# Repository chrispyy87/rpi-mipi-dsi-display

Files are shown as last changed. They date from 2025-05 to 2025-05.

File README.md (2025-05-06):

# rpi-mipi-dsi-display
Raspberry CM4 MIPI DSI display shield with LED driver for Midas MDT0500B1IH-MIPI display https://midasdisplays.com/shop/tft/mdt0500b1ih-mipi/ employing the ILI9881C display driver.
This shield serves as a example on how to implement alternative MIPI DSI displays to currently support ones.
PCBA manufacturing was realized by JLCPCB.

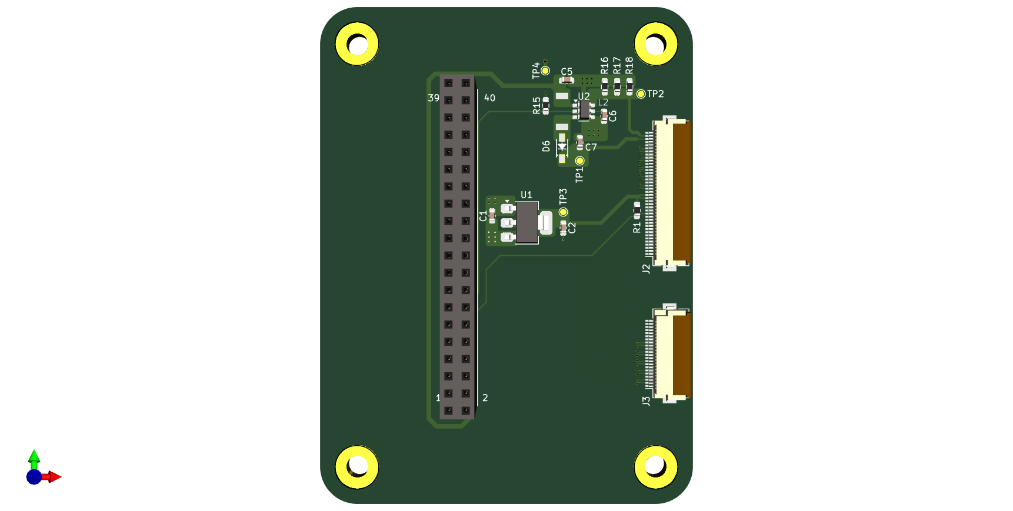
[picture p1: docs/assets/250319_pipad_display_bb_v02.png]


## Contents
- KiCAD schematics/board files: [CAD](CAD/)
- Gerber files: [rpi-mipi-dsi-display.zip](CAD/production/rpi-mipi-dsi-display.zip)
- PDF of schematics: [rpi-mipi-dsi-display.pdf](CAD/rpi-mipi-dsi-display.pdf)
- Bill of Materials: [rpi-mipi-dsi-display-BOM.xlsx](CAD/assembly/rpi-mipi-dsi-display-BOM.xlsx)
- KiCAD PCB and pick & place files: [rpi-mipi-dsi-display_CPL1.xlsx](CAD/assembly/rpi-mipi-dsi-display_CPL1.xlsx)

## Status
Working prototype with CM4 IO board running RPI OS Bookworm (64 bit).
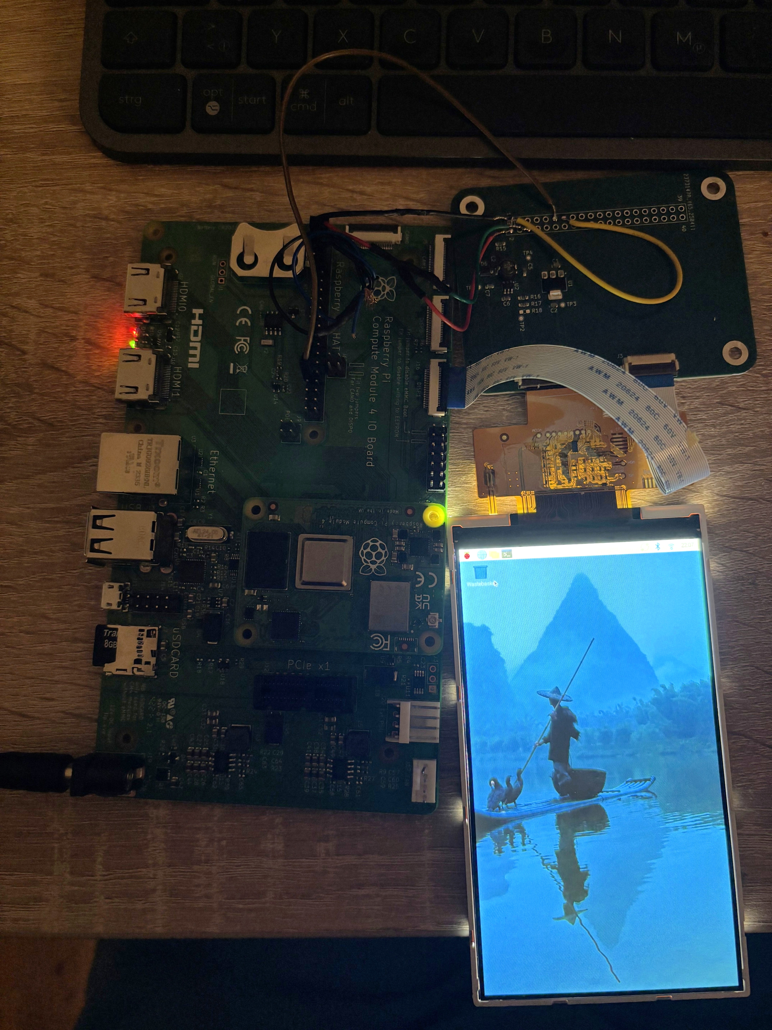
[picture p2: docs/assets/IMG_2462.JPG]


## Copyright and License
Schematic and PCB layout files are licensed under the CC BY 4.0 license.

THE DESIGN IS PROVIDED "AS IS" AND THE AUTHOR DISCLAIMS ALL WARRANTIES WITH REGARD TO THIS DESIGN INCLUDING ALL IMPLIED WARRANTIES OF MERCHANTABILITY AND FITNESS. IN NO EVENT SHALL THE AUTHOR BE LIABLE FOR ANY SPECIAL, DIRECT, INDIRECT, OR CONSEQUENTIAL DAMAGES OR ANY DAMAGES WHATSOEVER RESULTING FROM LOSS OF USE, DATA OR PROFITS, WHETHER IN AN ACTION OF CONTRACT, NEGLIGENCE OR OTHER TORTIOUS ACTION, ARISING OUT OF OR IN CONNECTION WITH THE USE OR PERFORMANCE OF THIS DESIGN.

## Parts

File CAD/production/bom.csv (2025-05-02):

Designator | Footprint | Quantity | Value | LCSC Part #
C1, C2 | 0603 | 2 | 22uF
C5, C6 | 0603 | 2 | 4.7uF
C7 | 0603 | 1 | 1uF
D6 | SOD-123 | 1 | MBR0540T1G
J1 | PinSocket_2x20_P2.54mm_Vertical | 1 | Conn_02x20_Odd_Even
J2 | Hirose_FH12-40S-0.5SH_1x40-1MP_P0.50mm_Horizontal_PiPad | 1 | Conn_01x40
J3 | Hirose_FH12-22S-0.5SH_1x22-1MP_P0.50mm_Horizontal_PiPad | 1 | Conn_01x22
L2 | SD53-100-R | 1 | 10uH 20%
R1, R15 | 0603 | 2 | 10k | RC0603FR-072K2L
R16 | 0603 | 1 | 2 | RC0603FR-072K2L
R17 | 0603 | 1 | 3.3 | RC0603FR-072K2L
TP1, TP2, TP3, TP4 | TestPoint_Pad_D1.0mm | 4 | TestPoint
U1 | SOT-223-3_TabPin2 | 1 | AMS1117-1.8
U2 | SOT-23-6 | 1 | TPS61165DBV

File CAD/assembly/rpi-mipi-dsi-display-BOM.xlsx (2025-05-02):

Comment | Designator | Footprint | JLCPCB Part #（optional）
MBR0540T1G | D6 |  | C21353
AMS1117-1.8 | U1 |  | C6185
TPS61165DBV | U2 |  | C58756
Hirose_FH12-22S-0.5SH_1x22-1MP_P0.50mm_Horizontal | J3 |  | C597981
Hirose_FH12-40S-0.5SH_1x40-1MP_P0.50mm_Horizontal | J2 |  | C202114
22uF | C1, C2 | 0603 | C59461
4.7uF | C5, C6 | 0603 | C19666
1uF | C7 | 0603 | C15849
10k | R1, R15 | 0603 | C25804
2 | R16 | 0603 | C22977
3.3 | R17 | 0603 | C22979
10uH 20% | L2 |  | C7309744

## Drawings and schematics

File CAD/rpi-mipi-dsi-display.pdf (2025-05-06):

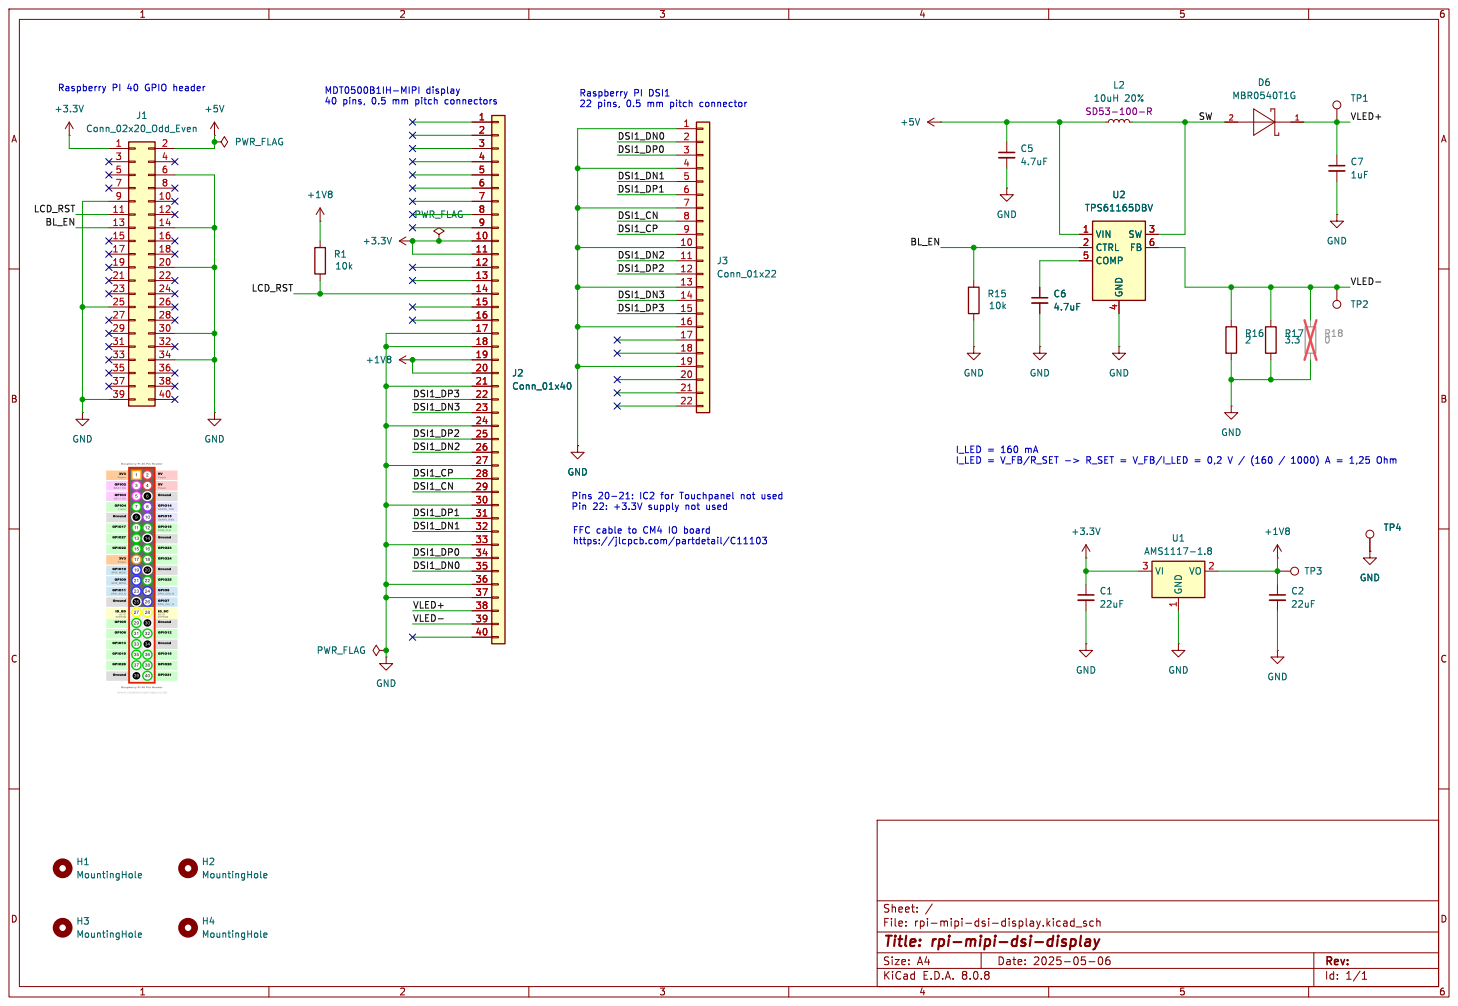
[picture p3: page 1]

Raspberry PI 40 GPIO header
+5V GND

22 pins, 0.5 mm pitch connector J2Conn_01x40

1 VO 2 VI 3 U1 AMS1117-1.8 DSI1_DN0 DSI1_DN3 DSI1_DN1 VLED+ VLED- BL_EN

File: rpi-mipi-dsi-display.kicad_sch Sheet: /
Id: 1/1 Title: rpi-mipi-dsi-display

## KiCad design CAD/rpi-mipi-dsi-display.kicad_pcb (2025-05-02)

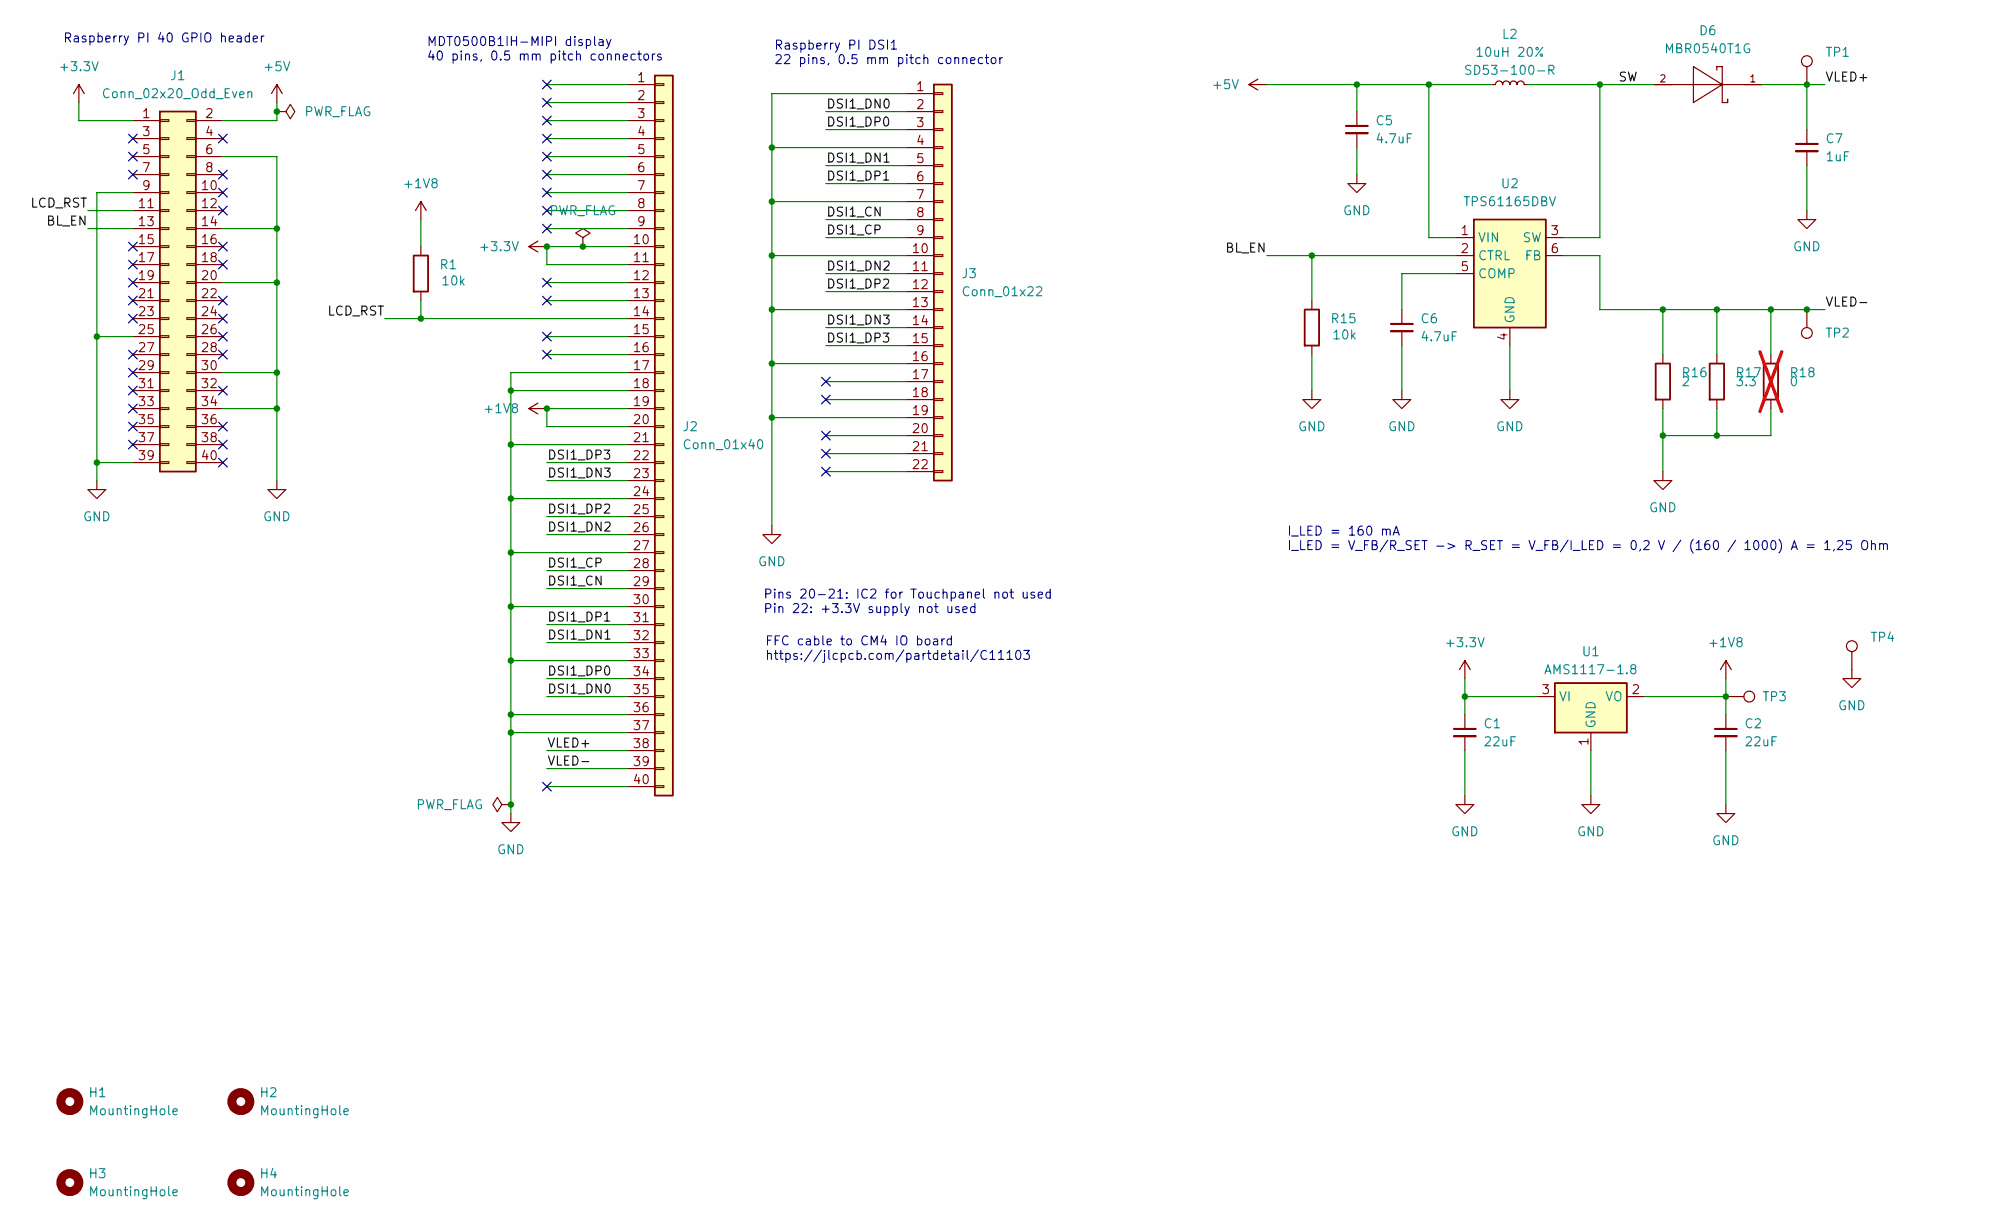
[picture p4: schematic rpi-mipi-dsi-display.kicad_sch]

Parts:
C1, C2: 22uF; C_0603_1608Metric
C5, C6: 4.7uF; C_0603_1608Metric
C7: 1uF; C_0603_1608Metric
D6: MBR0540T1G; SOD-123; MANUFACTURER_PART_NUMBER MBR0540T1G
H1, H2, H3, H4: MountingHole; MountingHole_3.5mm_Pad
J1: Conn_02x20_Odd_Even; PinSocket_2x20_P2.54mm_Vertical
J2: Conn_01x40; Hirose_FH12-40S-0.5SH_1x40-1MP_P0.50mm_Horizontal_PiPad
J3: Conn_01x22; Hirose_FH12-22S-0.5SH_1x22-1MP_P0.50mm_Horizontal_PiPad
L2: 10uH 20%; SD53-100-R
R1, R15: 10k; R_0603_1608Metric_Pad0.98x0.95mm_HandSolder; MPN RC0603FR-072K2L; Digi-Key_PN 311-2.20KHRCT-ND
R16: 2; R_0603_1608Metric_Pad0.98x0.95mm_HandSolder; MPN RC0603FR-072K2L; Digi-Key_PN 311-2.20KHRCT-ND
R17: 3.3; R_0603_1608Metric_Pad0.98x0.95mm_HandSolder; MPN RC0603FR-072K2L; Digi-Key_PN 311-2.20KHRCT-ND
R18: 0; R_0603_1608Metric_Pad0.98x0.95mm_HandSolder; MPN RC0603FR-072K2L; Digi-Key_PN 311-2.20KHRCT-ND; not fitted
TP1, TP2, TP3, TP4: TestPoint; TestPoint_Pad_D1.0mm
U1: AMS1117-1.8; SOT-223-3_TabPin2
U2: TPS61165DBV; SOT-23-6

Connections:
+1V8: C2.1, J2.19, J2.20, R1.1, TP3.1, U1.2 (VO)
+3.3V: C1.1, J1.1, J2.10, J2.11, U1.3 (VI)
+5V: C5.1, J1.2, L2.1, U2.1 (VIN)
/BL_EN: J1.13, R15.1, U2.2 (CTRL)
/DSI1_CN: J2.29, J3.8
/DSI1_CP: J2.28, J3.9
/DSI1_DN0: J2.35, J3.2
/DSI1_DN1: J2.32, J3.5
/DSI1_DN2: J2.26, J3.11
/DSI1_DN3: J2.23, J3.14
/DSI1_DP0: J2.34, J3.3
/DSI1_DP1: J2.31, J3.6
/DSI1_DP2: J2.25, J3.12
/DSI1_DP3: J2.22, J3.15
/LCD_RST: J1.11, J2.14, R1.2
/SW: D6.2, L2.2, U2.3 (SW)
/VLED+: C7.1, D6.1, J2.38, TP1.1
/VLED-: J2.39, R16.1, R17.1, R18.1, TP2.1, U2.6 (FB)
GND: C1.2, C2.2, C5.2, C6.2, C7.2, J1.6, J1.9, J1.14, J1.20, J1.25, J1.30, J1.34, J1.39, J2.17, J2.18, J2.21, J2.24, J2.27, J2.30, J2.33, J2.36, J2.37, J3.1, J3.4, J3.7, J3.10, J3.13, J3.16, J3.19, R15.2, R16.2, R17.2, R18.2, TP4.1, U1.1 (GND), U2.4 (GND)
unnamed: C6.1, U2.5 (COMP)

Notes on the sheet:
MDT0500B1IH-MIPI display 40 pins, 0.5 mm pitch connectors
Raspberry PI DSI1 22 pins, 0.5 mm pitch connector
I_LED = 160 mA I_LED = V_FB/R_SET -> R_SET = V_FB/I_LED = 0,2 V / (160 / 1000) A = 1,25 Ohm
FFC cable to CM4 IO board https://jlcpcb.com/partdetail/C11103
Raspberry PI 40 GPIO header
Pins 20-21: IC2 for Touchpanel not used Pin 22: +3.3V supply not used

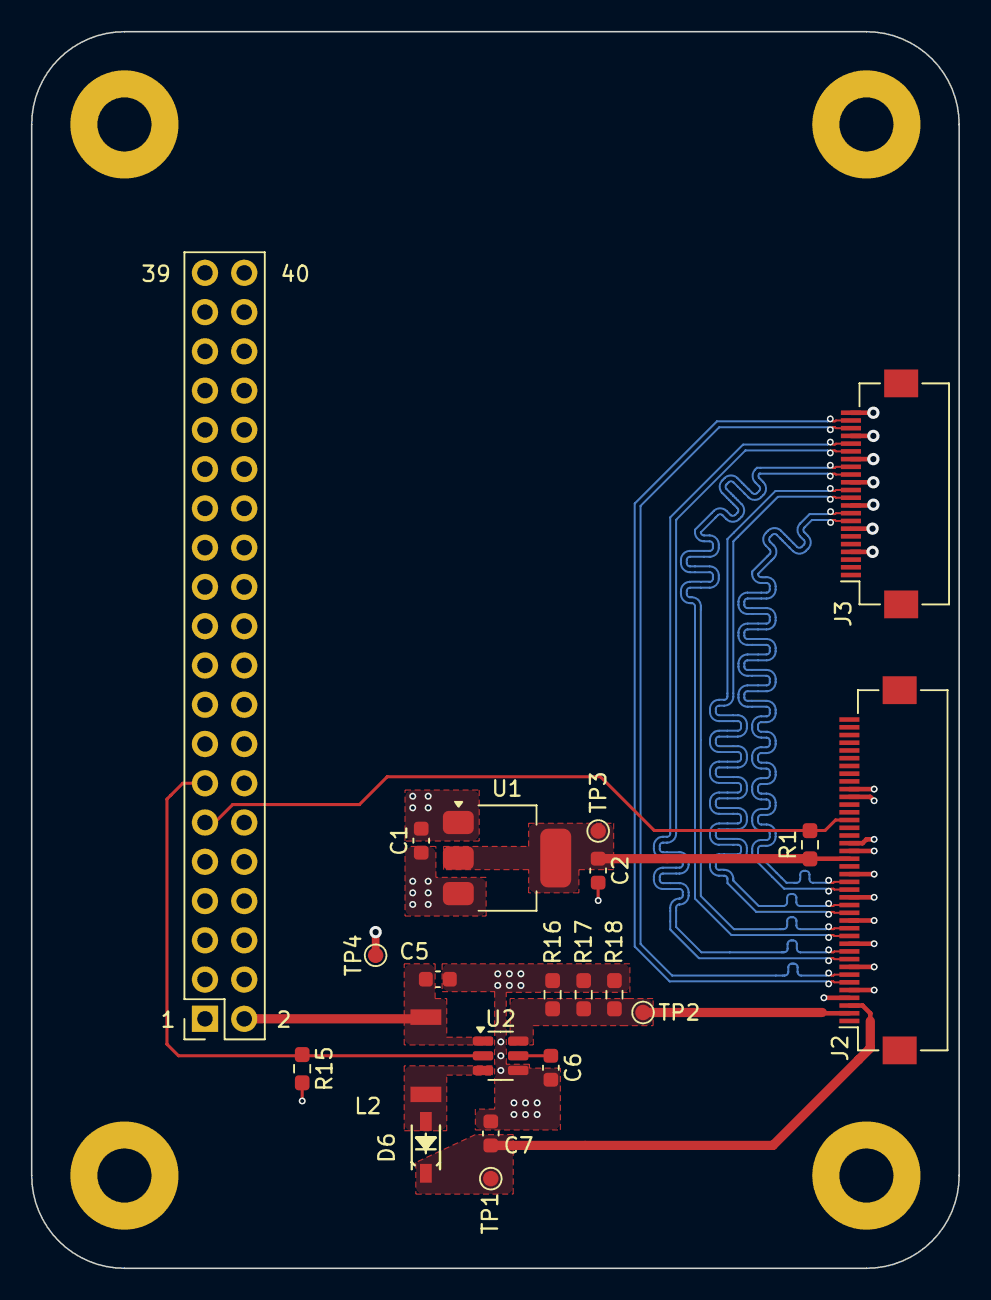
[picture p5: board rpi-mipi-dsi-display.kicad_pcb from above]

Board: 4 copper layers, 60.0 x 80.0 mm, 25 parts (0 on the bottom side), 20 nets.
